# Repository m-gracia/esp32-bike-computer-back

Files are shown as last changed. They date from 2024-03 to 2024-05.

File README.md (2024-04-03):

# esp32-bike-computer-back

## Synopsis
This is a companion for esp32-bike-computer-main that sends the distance measured by a VL53L0X laser ToF sensor.

This could be used as a parking sensor to show the perfect distance to the wall when you are parking backwards. If you find this completly unuseful there is another reason to have it: Why not?

## Part list
- **Seeduino Xiao ESP32-C3**</br>
I have choose this board because is the smallest I could find. The size is only 18mmx18mm.
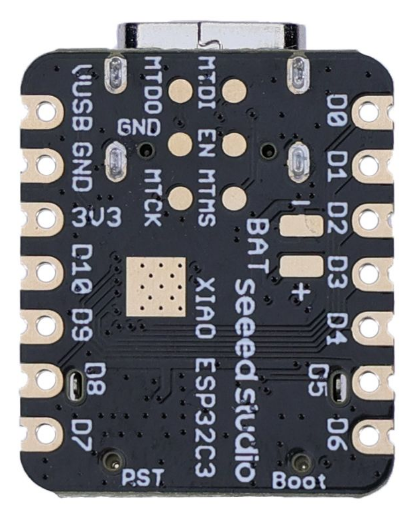
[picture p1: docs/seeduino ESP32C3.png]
ESP32-C3


- **VL53L0X sensor**</br>
An inexpensive laser ToF sensor with 2m range **with cover.**
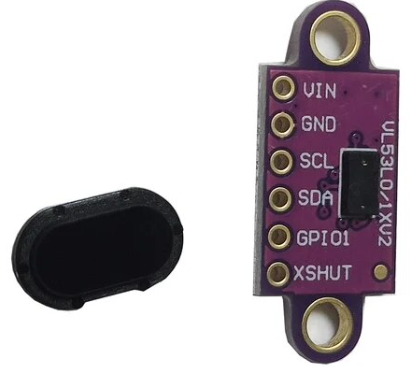
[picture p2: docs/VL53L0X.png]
VL53L0X


- **GoPro mount**</br>
Choose the one that fits better your setup on the bike. I have choose this one:
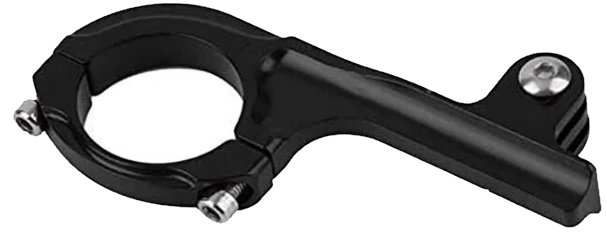
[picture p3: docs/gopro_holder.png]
GoPro-mount


## Scheme
The [Fritzing](https://fritzing.org/) scheme is located on the [schemes](schemes) folder. They are designed for soldering on a quick breadboard.
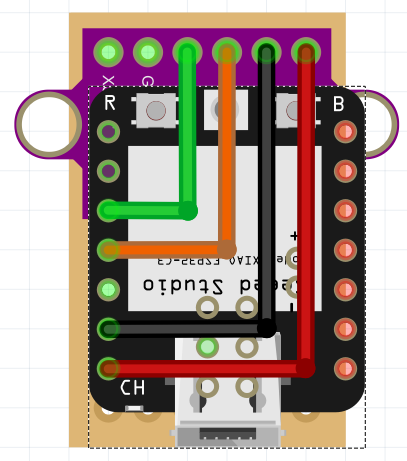
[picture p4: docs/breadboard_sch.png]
Breadboard_scheme

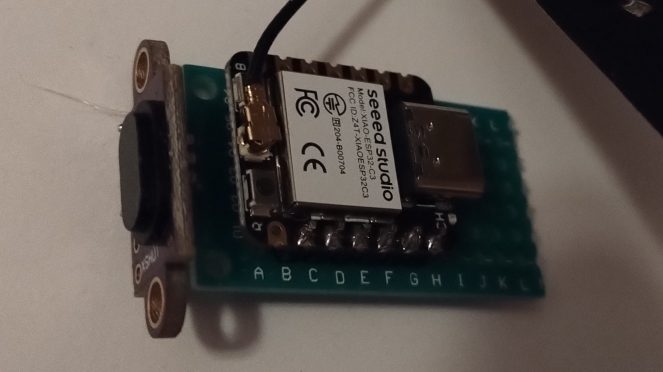
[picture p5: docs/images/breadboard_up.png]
Breadboard_up

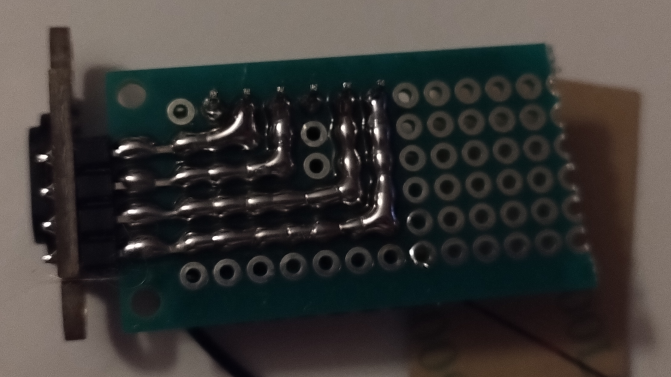
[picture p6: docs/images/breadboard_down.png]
Breadboard_down


## Waterproof case
I tried to use a JSN-SR04T ultrasonic sensor, the waterproof "brother" of the most known HC-SR04, but I could not take any acurate measurements. 

~~The workarround was keep the sensor and ESP32 inside of a waterproof case, make some holes for the sensor, usb cable and a gopro bracket and seal everything with silicone glue. I'm sure is not the perfect solution, neither is the best finnish, but I have no problem with it under rain or after cleaning the bike.~~

### UPDATE
I have made a 3D printed case for the ESP32-C3 and the VL53L0X sensor. You can find it at [3d_designs](3d_designs) folder.
- Printed on PETG
- 0,3mm layer height
- 100% infill
- No support required

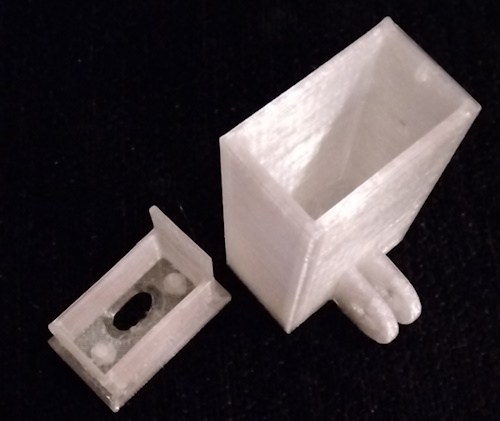
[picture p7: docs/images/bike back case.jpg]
Back case


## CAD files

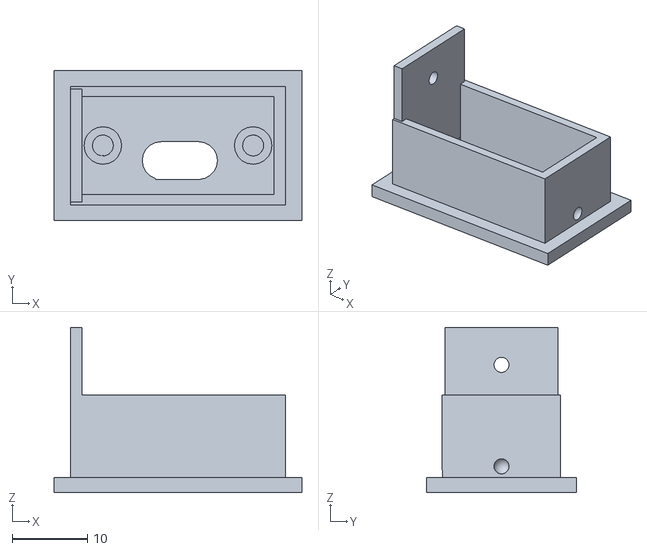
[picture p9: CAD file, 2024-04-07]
3d_designs/bike-back-case front.stl
33.0 x 20.0 x 22.0

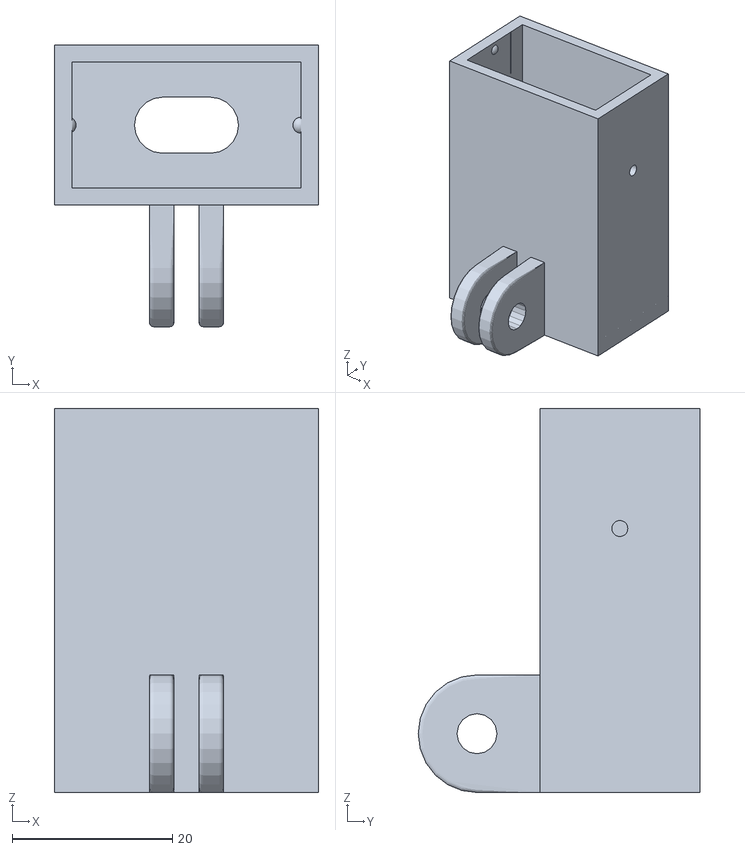
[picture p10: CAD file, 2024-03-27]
3d_designs/bike-back-case back.stl
33.0 x 35.2 x 48.0

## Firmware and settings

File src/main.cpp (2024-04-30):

#include <Arduino.h>
#include "my_def.h"
#include "my_debug.h"
#include "distance.h"
#include "bluetooth.h"

void setup() {
  #ifdef DEBUG
    Serial.begin(115200);
  #endif
  DEBUG_PRINTLN("Manuel Gracia.Apr-2024");
  DEBUG_PRINTLN("https://github.com/m-gracia");
  DEBUG_PRINTLN("esp32-bike-computer-back_20240429");
  
  initDistance();
  initBT();

  DEBUG_PRINTLN("Setup end");
}

void loop() {
  if (timerDistance < millis()){
    getDistance();
    timerDistance = millis() + 200; // 200ms
  }
  
  if (bikeBT == STATUS_OK){
    if (bikeDataChanged != 0){
      if (sendBT()){ bikeDataChanged=0; DEBUG_BT_PRINTLN("BT SENT");}
    }
  } else if (bikeBT == STATUS_WARN){
    DEBUG_BT_PRINTLN("BT WARNING. Connecting");
    connectBT();
  } else if (timerBT < millis()){
    timerBT = millis() + 5000; // 5sec
    DEBUG_BT_PRINTLN("BT CRIT. Initalyzinng");
    initBT();
  }
}

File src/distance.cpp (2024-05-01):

#include "distance.h"
#include "my_def.h"
#include "my_debug.h"

void initDistance(){
  if (!Wire.setPins(I2C_SDA, I2C_SCL)) DEBUG_SENSOR_PRINTLN("I2C init failed");
  else if(!tofDev.begin()) DEBUG_SENSOR_PRINTLN("Sensor init failed. Not found");
  else if(!tofDev.configSensor(TOF_SENSE)) DEBUG_SENSOR_PRINTLN("Sensor config failed");
  //else if(!tofDev.startRangeContinuous(TOF_PERIOD)) DEBUG_SENSOR_PRINTLN("Sensor start range failed");
  else DEBUG_SENSOR_PRINTLN("Sensor init OK");
}

void getDistance(){
  VL53L0X_RangingMeasurementData_t measure;
  unsigned char distanceEcho;   // Distance measured in cm
  unsigned char tbikeDistance;

  tofDev.rangingTest(&measure, false); // pass in 'true' to get debug data printout

  if (tofDev.readRangeStatus() == VL53L0X_ERROR_NONE && measure.RangeStatus != 4) 
    distanceEcho = measure.RangeMilliMeter/10;
  else 
    distanceEcho = 255;
  if (distanceEcho == 0) distanceEcho = 255; // Sometimes it report a false 0mm distance

  DEBUG_SENSOR_PRINT("Distance: ");
  DEBUG_SENSOR_PRINTLN(distanceEcho);

  if (distanceEcho < distanceMark1) tbikeDistance = 5;      // Closest
  else if (distanceEcho < distanceMark2) tbikeDistance = 4; 
  else if (distanceEcho < distanceMark3) tbikeDistance = 3;
  else if (distanceEcho < distanceMark4) tbikeDistance = 2;
  else if (distanceEcho < distanceMark) tbikeDistance = 1;  // Farthest
  else tbikeDistance = STATUS_OK; // No detection or too far
  
  DEBUG_SENSOR_PRINT("Distance mark: ");
  DEBUG_SENSOR_PRINTLN(tbikeDistance);

  if (tbikeDistance != bikeDistance){
    bitSet(bikeDataChanged,15);
    bikeDistance = tbikeDistance;
  }
}

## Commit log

2024-03-01 Using ESP32-C3 so removed dualcore tasks. Distance function changes to use VL53L0x sensor.
2024-03-23 Changed I2C pins and VL53L0x configuration
2024-03-23 Breadboard schematic
    [back_v1.fzz]
2024-03-25 added 3d print case
    [bike-back-case back.stl, bike-back-case front.stl]
2024-03-27 Updated 3d back design
    [bike-back-case back.stl]
2024-04-03 Updated documentation
    [back.fzz]
2024-04-07 Updated front 3d case
    [bike-back-case front.stl]
